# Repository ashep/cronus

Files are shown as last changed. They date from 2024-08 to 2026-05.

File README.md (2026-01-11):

# Cronus

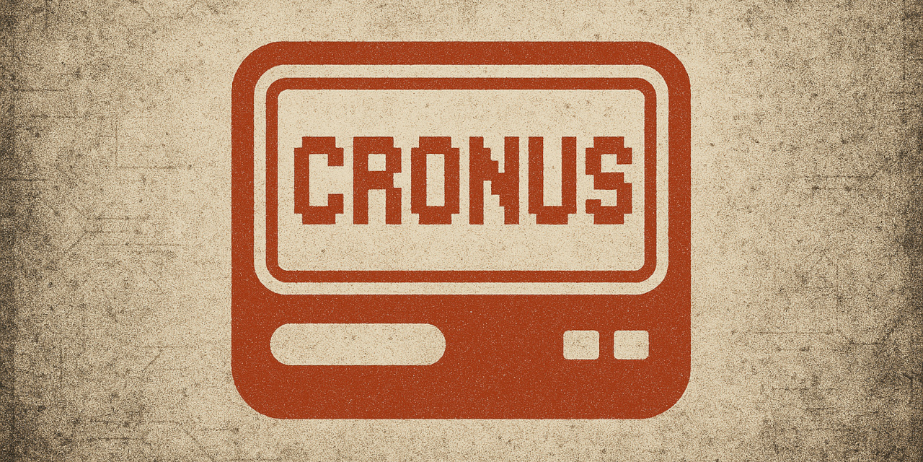
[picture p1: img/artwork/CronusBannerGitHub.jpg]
Banner


**Cronus** is a minimalistic digital clock built on top of the ESP32 MCU with the following features in mind.

- Show the current time, date, and weather conditions.
- Simple, with a bright display.
- Brightness auto-adjustment depending on the ambient light level.
- No buttons.
- Automatic Over-the-Air firmware upgrades.
- No disgusting bloody Arduino.

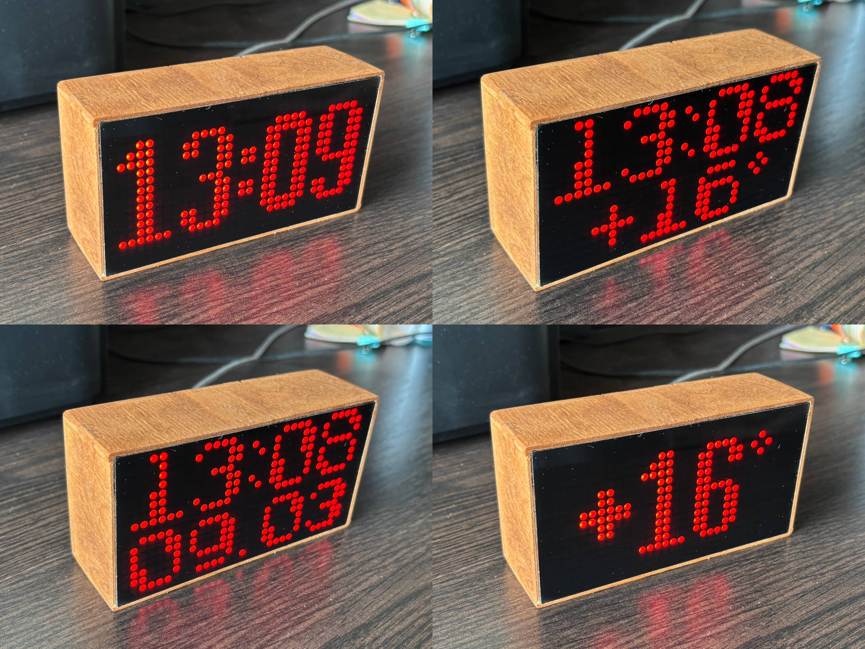
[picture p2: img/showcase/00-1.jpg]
Showcase

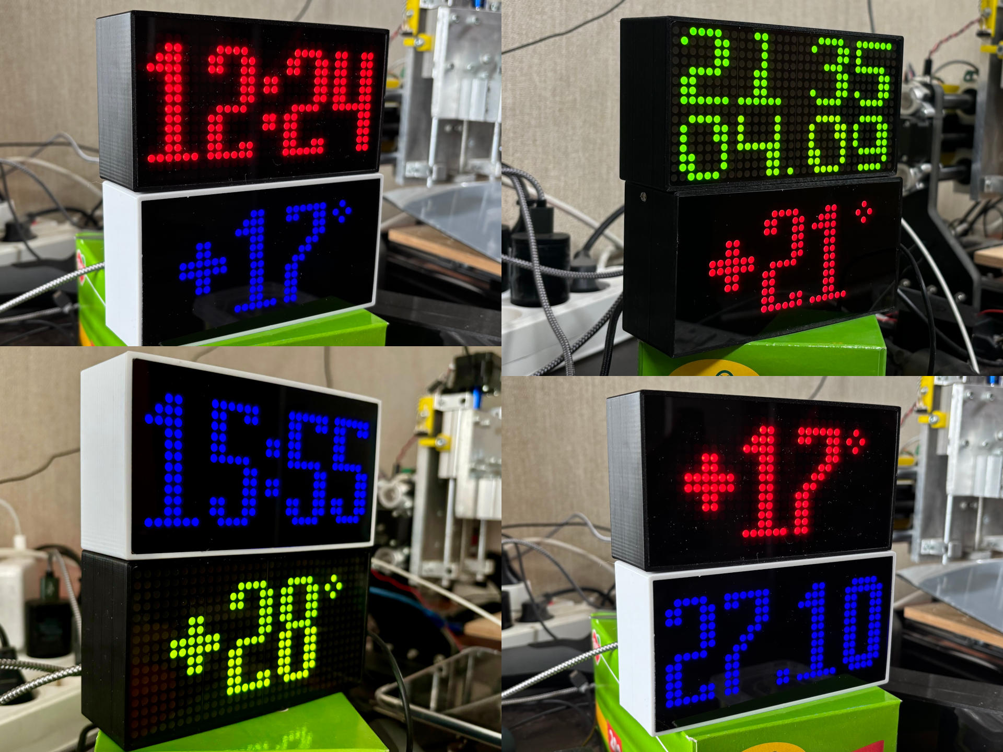
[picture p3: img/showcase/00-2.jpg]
Showcase


<details>
<summary>See more</summary>

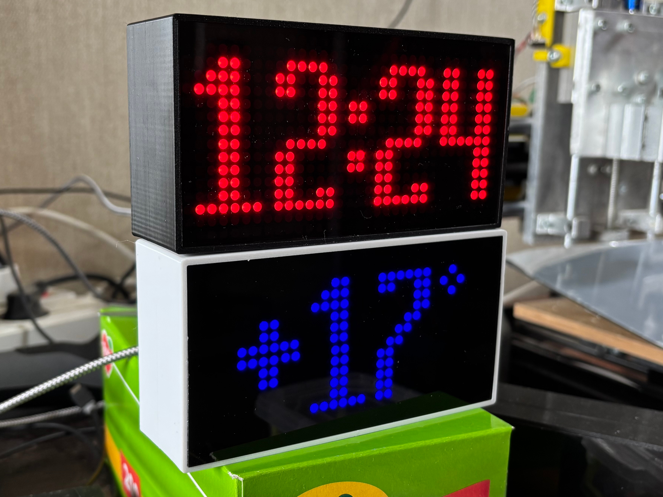
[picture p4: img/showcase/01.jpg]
Showcase

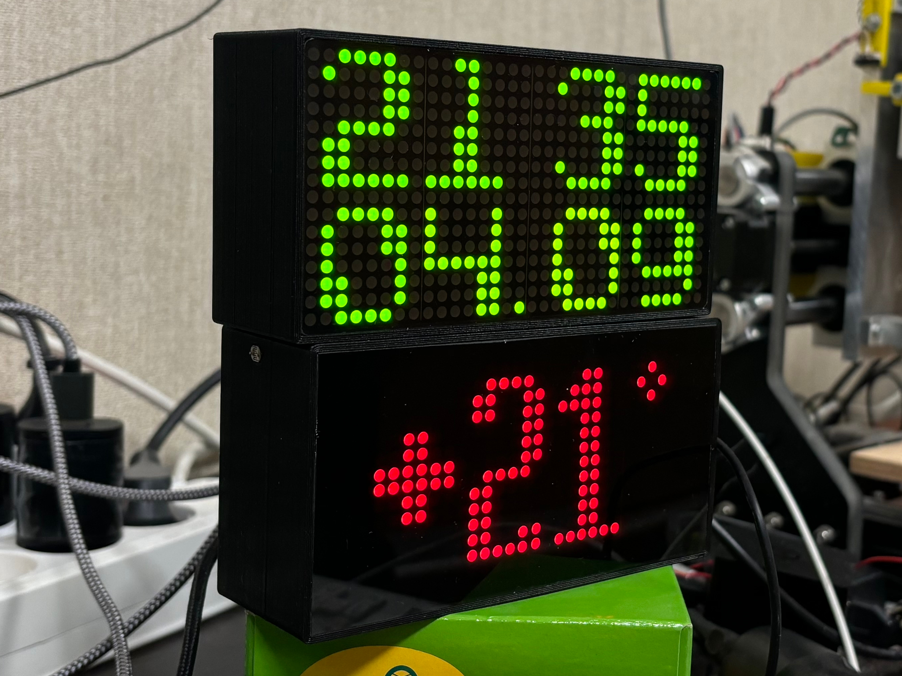
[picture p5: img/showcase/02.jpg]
Showcase

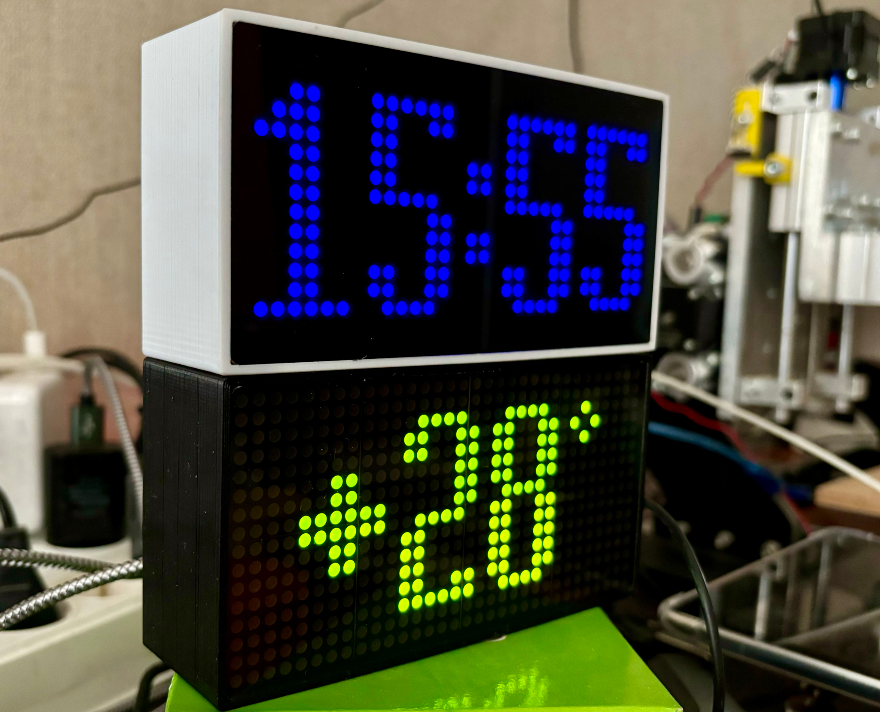
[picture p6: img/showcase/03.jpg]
Showcase

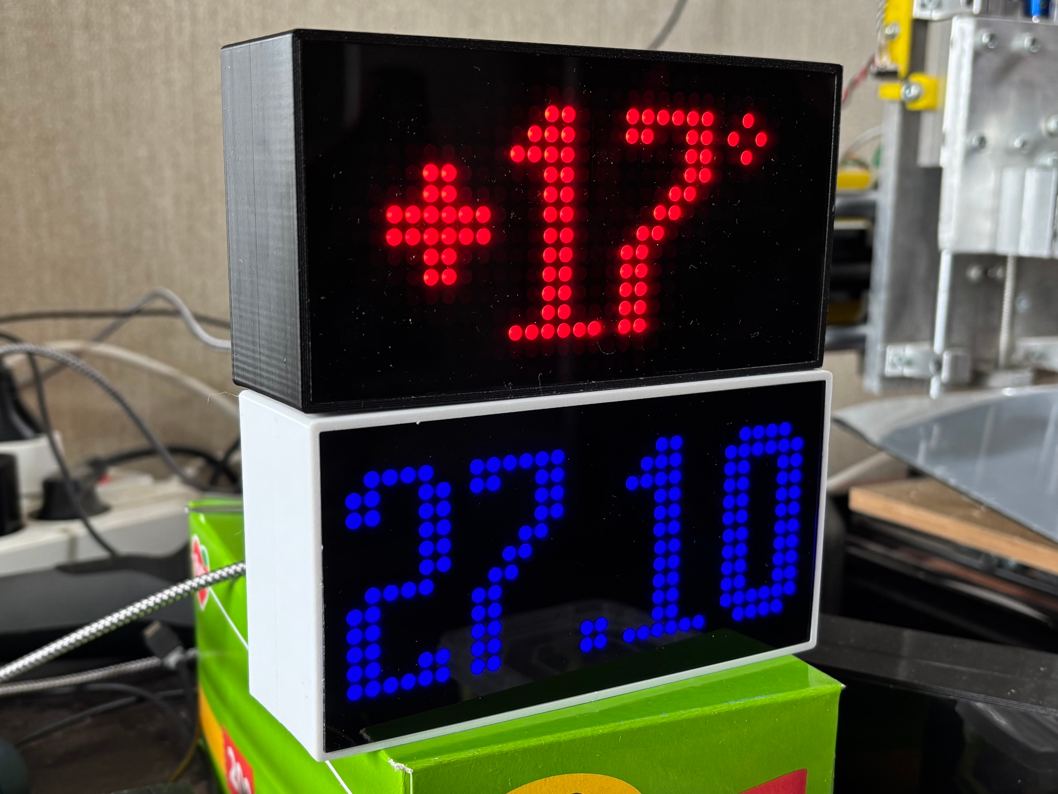
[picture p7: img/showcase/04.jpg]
Showcase

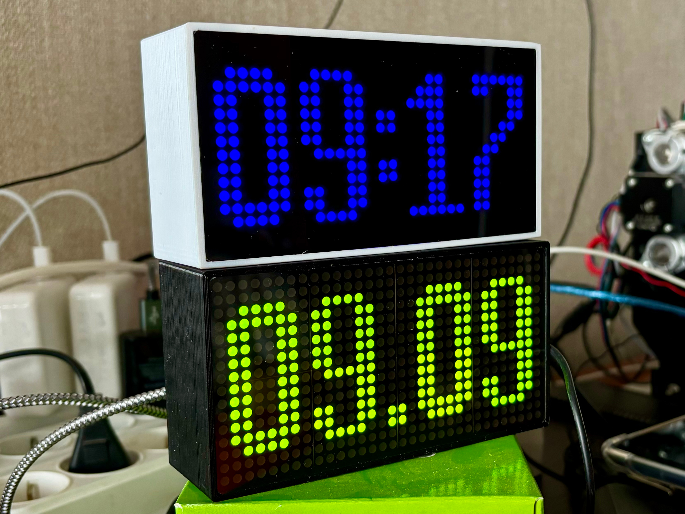
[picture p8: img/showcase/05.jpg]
Showcase

</details>

## How to make it

See the [Wiki](https://github.com/ashep/cronus/wiki).

## Contributing

Clone the repo:

```shell
git clone --recurse-submodules https://github.com/ashep/cronus.git
```

Or update an already cloned one to the latest version:

```shell
git pull
git submodule update --recursive --remote
```

## Changelog

### 0.0.5 (2026-01-11)

- Added [air raid alerts widget](https://github.com/ashep/cronus/issues/32).
- Added [a "busy" icon upon OTA](https://github.com/ashep/cronus/issues/23).
- Performance improvements and little optimizations.

### 0.0.4 (2025-09-30)

- Added [widget color](https://github.com/ashep/cronus/issues/26) options for colorful screens.
- Added [night mode](https://github.com/ashep/cronus/issues/28) options for colorful screens.

### 0.0.3 (2025-08-31)

- Added [night mode](https://github.com/ashep/cronus/issues/21) for colorful screens.
- Added [custom location](https://github.com/ashep/cronus/issues/13) option.
- Fixed [Wi-Fi reconnection](https://github.com/ashep/cronus/issues/18) at startup.

### 0.0.2 (2025-08-11)

- New Bluetooth configuration interface added.
- Weather icons added.

### 0.0.1 (2025-06-21)

First stable release.

## Authors

- [Oleksandr Shepetko](https://shepetko.com).

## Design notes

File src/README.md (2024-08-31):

# Cronus Firmware

## How to build

1. Install and [set up ESP-IDF].
2. `idf.py menuconfig`
3. Go to `Component config -> Cronus`, make necessary changes.
4. Exit saving changes.
5. `idf.py build`
6. `idf.py flash`

[set up ESP-IDF]: https://docs.espressif.com/projects/esp-idf/en/stable/esp32/get-started/index.html#installation

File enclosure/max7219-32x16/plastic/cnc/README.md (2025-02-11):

# Cronus Front Glass

This G-code is made for CNC milling of 2.4 mm acrylic glass using a 1 mm flute bit.

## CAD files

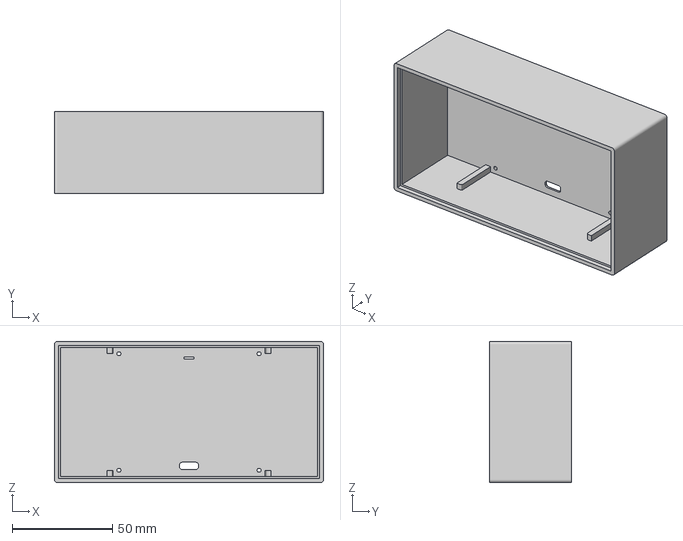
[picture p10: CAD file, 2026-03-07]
enclosure/max7219-32x16/plastic/3d-print/Enclosure.3mf
134.4 x 41.0 x 70.6 mm

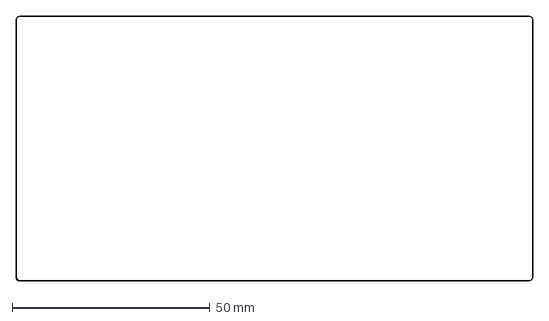
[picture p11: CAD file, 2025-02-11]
enclosure/max7219-32x16/plastic/dxf/FrontGlass.dxf
130.4 x 66.8 mm

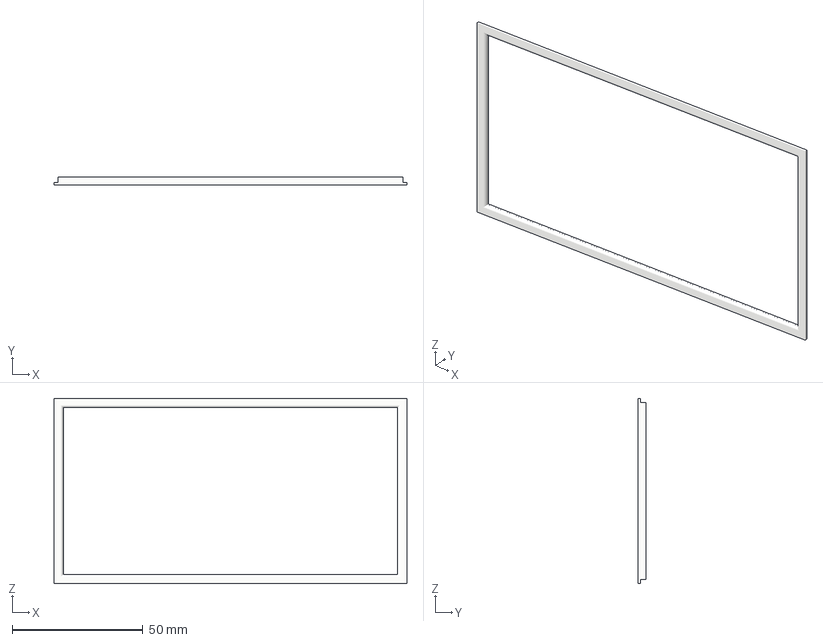
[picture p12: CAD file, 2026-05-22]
enclosure/max7219-32x16/plywood/3d-print/FrontGlassShim.3mf
135.0 x 2.90 x 70.8 mm

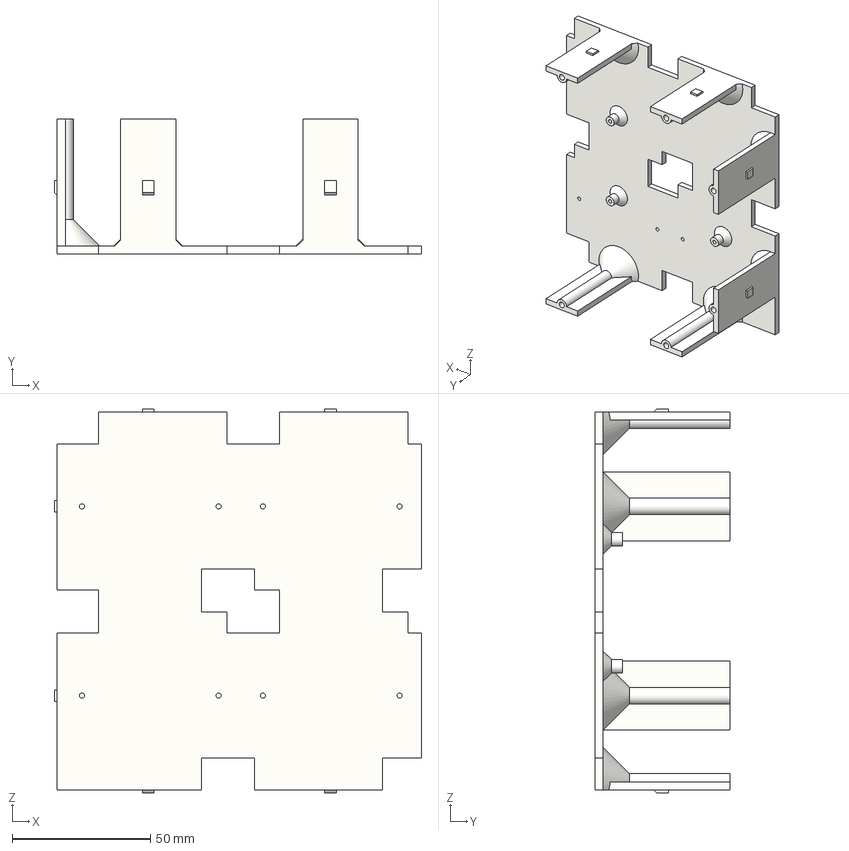
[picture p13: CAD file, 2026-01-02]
enclosure/ws2812-32x16/3d-print/DisplayMountLeft.3mf
133.0 x 49.0 x 139.0 mm

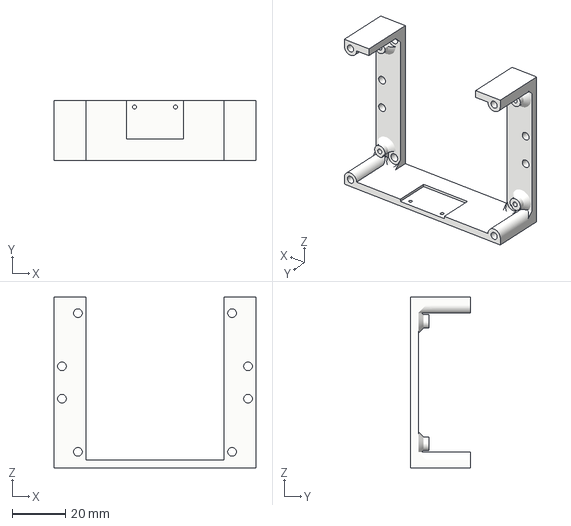
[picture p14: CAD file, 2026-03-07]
enclosure/max7219-32x16/plastic/3d-print/DisplayMount.3mf
76.0 x 22.7 x 64.2 mm

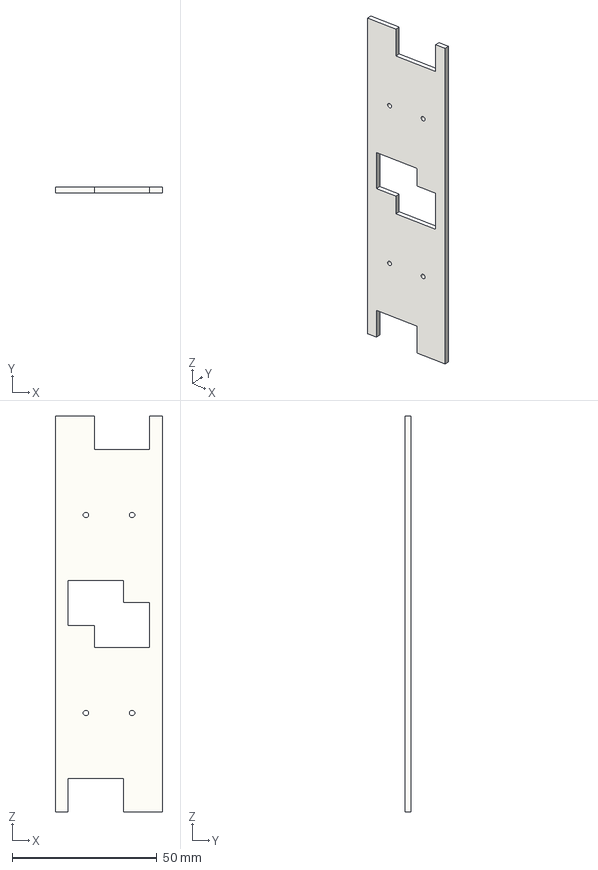
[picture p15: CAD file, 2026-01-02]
enclosure/ws2812-32x16/3d-print/DisplayMountConnector.3mf
37.0 x 2.00 x 137.0 mm

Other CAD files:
enclosure/ws2812-32x16/3d-print/DisplayMountRight.3mf
enclosure/max7219-32x16/plastic/CronusPlastic.f3d
enclosure/ws2812-32x16/Cronus.f3d

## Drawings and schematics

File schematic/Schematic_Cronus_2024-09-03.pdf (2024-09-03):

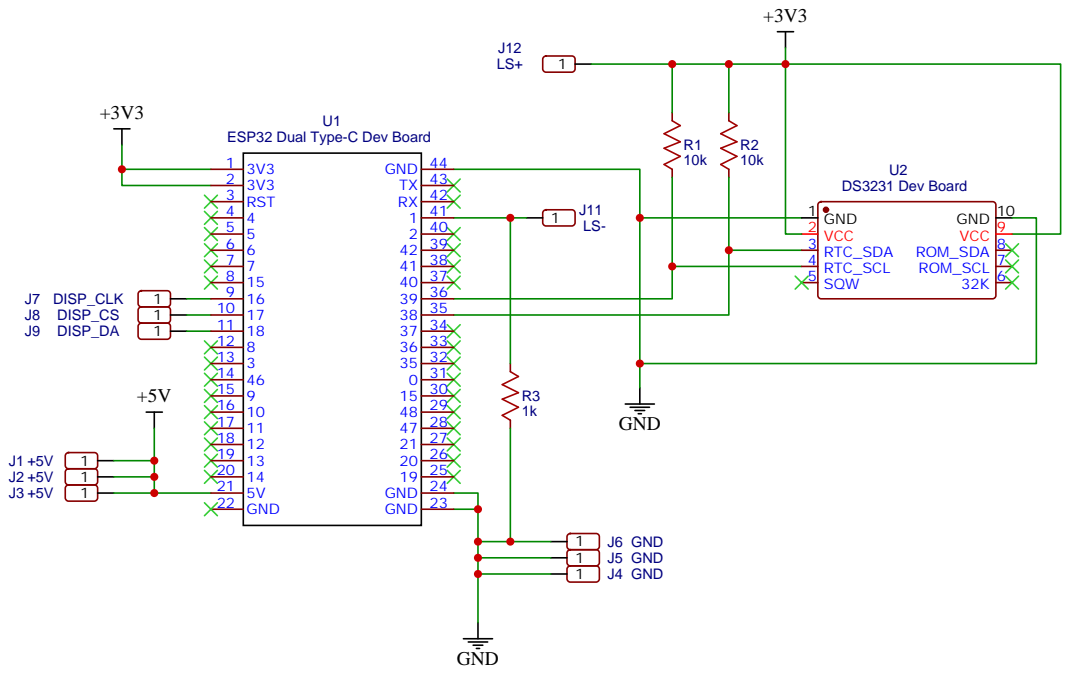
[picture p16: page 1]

Drawn By: Oleksandr Shepetko

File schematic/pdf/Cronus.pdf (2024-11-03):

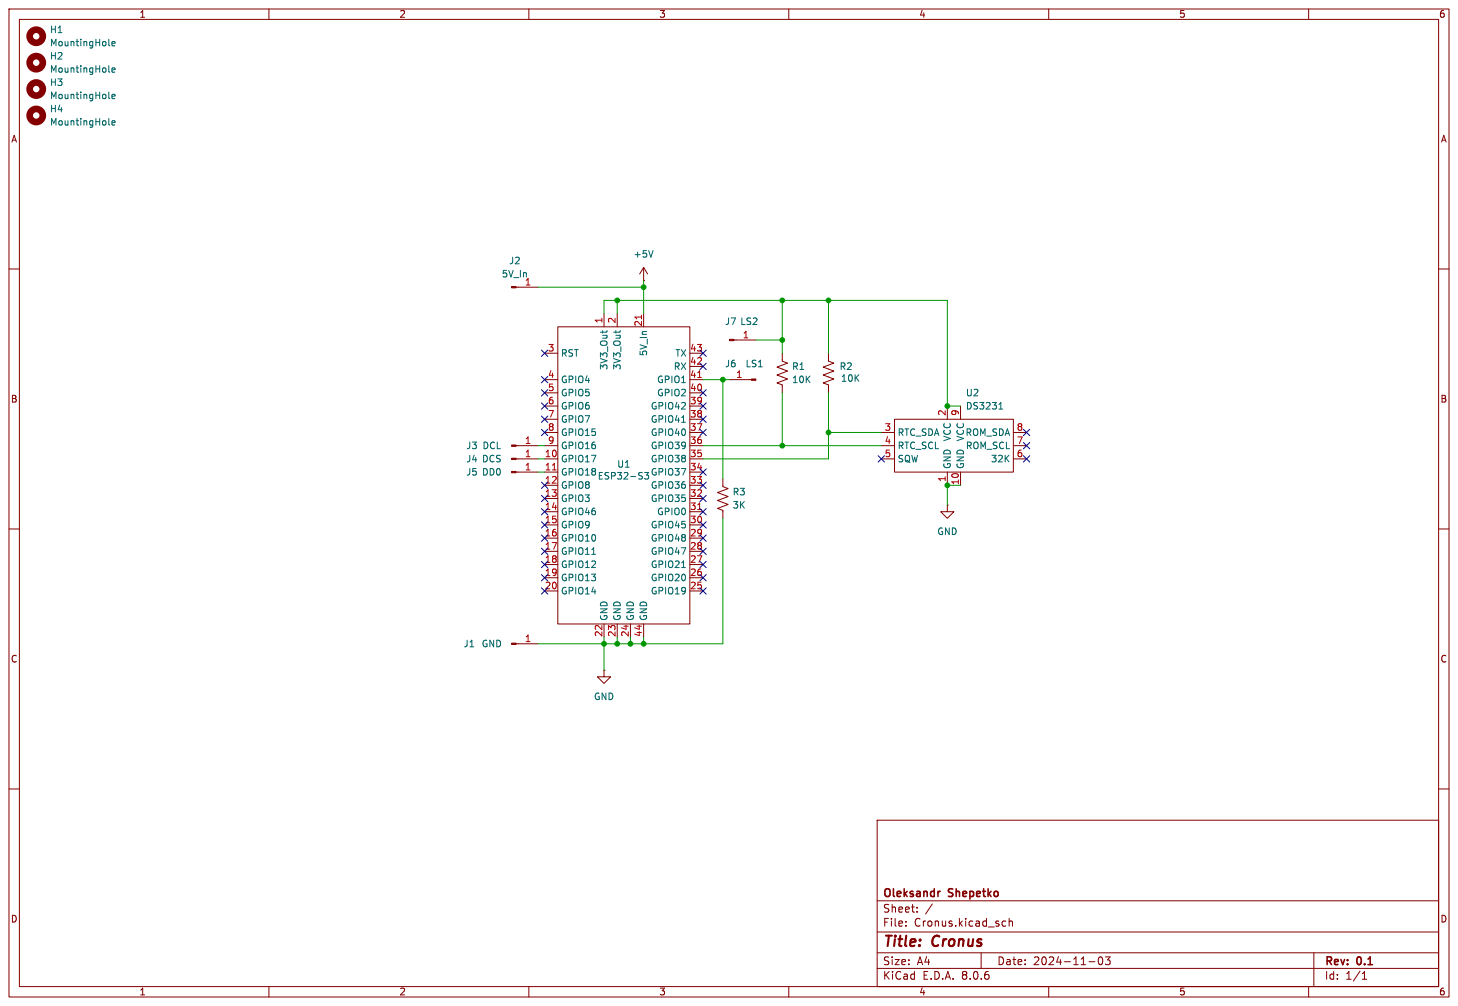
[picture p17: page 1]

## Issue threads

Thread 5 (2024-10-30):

Boot is halted in case if external RTC does not respond

ashep, 2024-10-30:

ashep, 2024-11-03:
Fixed in https://github.com/ashep/d5y/commit/fec575ab20989c3dba0f918175b4d31171c15e7e

Closed 2024-11-03.

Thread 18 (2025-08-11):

Add Wi-Fi reconnection attempts at startup

ashep, 2025-08-11:
If the first Wi-Fi connection attempt fails at the boot stage, the device should keep trying to reconnect.

It should only do this if the Wi-Fi connection was previously configured.

Closed 2025-08-31.

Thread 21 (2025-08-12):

Add night mode for screens displays

ashep, 2025-08-12:
WS2812 5mm LEDs are too bright in a dark room when emitting combined colors of light, i.e., not a single-channel color, like R, G, or B.

The idea is to have a "night mode": when the light sensor reports a zero light level, the display is automatically switched to a single-color mode. The best color is red, but users should be able to set it up.

The first iteration can use a fixed red color and an always-enabled night mode.

Closed 2025-08-12.

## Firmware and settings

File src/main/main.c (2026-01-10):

#include "cronus/cfg.h"
#include "cronus/bt.h"
#include "cronus/weather.h"
#include "cronus/air_raid.h"
#include "cronus/screen.h"
#include "cronus/brightness.h"

#ifdef CONFIG_CRONUS_DISPLAY_0_DRIVER_MAX7219_32X16
#include "dy/display_driver_max7219.h"
#elifdef CONFIG_CRONUS_DISPLAY_0_DRIVER_WS2812_32X16
#include "dy/display_driver_ws2812.h"
#endif

#include <string.h>
#include "esp_log.h"
#include "esp_event.h"
#include "nvs.h"
#include "nvs_flash.h"
#include "dy/error.h"
#include "dy/appinfo.h"
#include "dy/cfg2.h"
#include "dy/rtc.h"
#include "dy/net.h"
#include "dy/net_cfg.h"
#include "dy/ds3231.h"
#include "dy/cloud.h"

#define LTAG "MAIN"

static dy_ds3231_handle_t ds3231;

static dy_err_t init_nvs() {
    esp_err_t esp_err;

    esp_err = nvs_flash_init();
    if (esp_err == ESP_ERR_NVS_NO_FREE_PAGES || esp_err == ESP_ERR_NVS_NEW_VERSION_FOUND) {
        if ((esp_err == nvs_flash_erase()) != ESP_OK) {
            return dy_err(DY_ERR_FAILED, "nvs_flash_erase failed: %s", esp_err_to_name(esp_err));
        }

        if ((esp_err == nvs_flash_init()) != ESP_OK) {
            return dy_err(DY_ERR_FAILED, "nvs_flash_init failed: %s", esp_err_to_name(esp_err));
        }
    } else if (esp_err != ESP_OK) {
        return dy_err(DY_ERR_FAILED, "nvs_flash_init failed: %s", esp_err_to_name(esp_err));
    }

    return dy_ok();
}

static dy_err_t init_rtc() {
    dy_err_t err;
#ifdef CONFIG_CRONUS_DS3231_ENABLED
    err = dy_ds3231_init(CONFIG_CRONUS_DS3231_PIN_SCL, CONFIG_CRONUS_DS3231_PIN_SDA, &ds3231);
    if (dy_is_err(err)) {
        return err;
    }
    ESP_LOGI(LTAG, "DS3231 initialized; scl=%d; sda=%d", CONFIG_CRONUS_DS3231_PIN_SCL, CONFIG_CRONUS_DS3231_PIN_SDA);

    if (dy_is_err(err = dy_rtc_init(&ds3231))) {
        return err;
    }
#else
        if (dy_is_err(err = dy_rtc_init(NULL))) {
            return err;
        }
#endif

    ESP_LOGI(LTAG, "RTC initialized");

    return dy_ok();
}

#ifdef CONFIG_CRONUS_DISPLAY_0_DRIVER_MAX7219_32X16

static dy_err_t init_display_max7219() {
    dy_err_t err = dy_display_driver_max7219_init(
        0,
        CONFIG_CRONUS_DISPLAY_0_DRIVER_MAX7219_32X16_PIN_CS,
        CONFIG_CRONUS_DISPLAY_0_DRIVER_MAX7219_32X16_PIN_CLK,
        CONFIG_CRONUS_DISPLAY_0_DRIVER_MAX7219_32X16_PIN_DATA,
        4,
        2,
        true
    );
    if (dy_is_err(err)) {
        return err;
    }

    ESP_LOGI(LTAG, "MAX7219 display driver initialized; cs=%d; clk=%d; data=%d",
             CONFIG_CRONUS_DISPLAY_0_DRIVER_MAX7219_32X16_PIN_CS,
             CONFIG_CRONUS_DISPLAY_0_DRIVER_MAX7219_32X16_PIN_CLK,
             CONFIG_CRONUS_DISPLAY_0_DRIVER_MAX7219_32X16_PIN_DATA
    );

    return dy_ok();
}

#endif // CONFIG_CRONUS_DISPLAY_0_DRIVER_MAX7219_32X16

#ifdef CONFIG_CRONUS_DISPLAY_0_DRIVER_WS2812_32X16

static dy_err_t init_display_ws2812() {
    dy_err_t err = dy_display_driver_ws2812_init(
        0,
        CONFIG_CRONUS_DISPLAY_0_DRIVER_WS2812_32X16_PIN_DATA,
        (dy_display_driver_ws2812_segments_config_t) {
            .ppx = 8,
            .ppy = 8,
            .cols = 4,
            .rows = 2,
        });
    if (dy_is_err(err)) {
        return err;
    }

    ESP_LOGI(LTAG, "WS2812 display driver initialized; data=%d; nx=%d; ny=%d",
             CONFIG_CRONUS_DISPLAY_0_DRIVER_WS2812_32X16_PIN_DATA, 4, 2);

    return dy_ok();
}

#endif // CONFIG_CRONUS_DISPLAY_0_DRIVER_WS2812_32X16

static dy_err_t init_display() {
    dy_err_t err;
#ifdef CONFIG_CRONUS_DISPLAY_0_DRIVER_MAX7219_32X16
    err = init_display_max7219();
#elifdef CONFIG_CRONUS_DISPLAY_0_DRIVER_WS2812_32X16
    err = init_display_ws2812();
#else
    err = dy_err(DY_ERR_NOT_CONFIGURED, "no display driver set");
#endif

    return err;
}

static char *hwid() {
#ifdef CONFIG_CRONUS_DISPLAY_0_DRIVER_MAX7219_32X16
    return "max7219v32x16";
#elifdef CONFIG_CRONUS_DISPLAY_0_DRIVER_WS2812_32X16
    return "ws2812v32x16";
#else
    return "unknown";
#endif
}

void app_main(void) {
    esp_err_t esp_err;
    dy_err_t err;

    int v_maj, v_min, v_patch, v_alpha;
    int sn = sscanf(APP_VERSION, "%d.%d.%d.%d", &v_maj, &v_min, &v_patch, &v_alpha);
    if (sn == 3) {
        v_alpha = 0;
    } else if (sn != 4) {
        v_maj = 0;
        v_min = 0;
        v_patch = 0;
    }
    ESP_LOGI(LTAG, "APP_VERSION: %s; parsed: %d.%d.%d.%d", APP_VERSION, v_maj, v_min, v_patch, v_alpha);

    // App info, MUST be set before any other operations
    dy_appinfo_info_t app_info = {
        .owner = APP_OWNER,
        .name = APP_NAME,
        .hwid = hwid(),
        .ver = {
            .major = v_maj,
            .minor = v_min,
            .patch = v_patch,
            .alpha = v_alpha,
        },
        .auth = "", // will be set later
    };
    dy_appinfo_set(&app_info);

    // Event loop
    if ((esp_err = esp_event_loop_create_default()) != ESP_OK) {
        ESP_LOGE(LTAG, "esp_event_loop_create_default: %s", esp_err_to_name(esp_err));
        abort();
    }

    // NVS
    if (dy_is_err(err = init_nvs())) {
        ESP_LOGE(LTAG, "init_nvs: %s", dy_err_str(err));
        abort();
    }

    // Config, MUST be called right AFTER init_nvs(), but BEFORE further initialization
    if (dy_is_err(err = init_config())) {
        ESP_LOGE(LTAG, "init_config: %s", dy_err_str(err));
        abort();
    }

    float lat = 0;
    if (dy_is_err(err = dy_cfg2_get_float_dft(CRONUS_CFG_ID_LOCATION_LAT, &lat, 0))) {
        ESP_LOGE(LTAG, "dy_cfg2_get_float(CRONUS_CFG_ID_LOCATION_LAT): %s", dy_err_str(err));
    }
    float lng = 0;
    if (dy_is_err(err = dy_cfg2_get_float_dft(CRONUS_CFG_ID_LOCATION_LNG, &lng, 0))) {
        ESP_LOGE(LTAG, "dy_cfg2_get_float(CRONUS_CFG_ID_LOCATION_LNG): %s", dy_err_str(err));
    }
    dy_cloud_set_location(lat, lng);

    // Display
    if (dy_is_err(err = init_display())) {
        ESP_LOGE(LTAG, "init_display: %s", dy_err_str(err));
        abort();
    }

    // RTC
    if (dy_is_err(err = init_rtc())) {
        ESP_LOGE(LTAG, "init_rtc: %s", dy_err_str(err));
    }

    // Network
    if (dy_is_err(err = dy_net_init())) {
        ESP_LOGE(LTAG, "dy_net_init: %s", dy_err_str(err));
        abort();
    }

    // Network config service
    if (dy_is_err(err = dy_net_cfg_init())) {
        ESP_LOGE(LTAG, "dy_net_cfg_init: %s", dy_err_str(err));
    }

    // Bluetooth
    if (dy_is_err(err = cronus_bt_init())) {
        ESP_LOGE(LTAG, "cronus_bt_init: %s", dy_err_str(err));
    }

    // Time sync
    if (dy_is_err(err = dy_cloud_time_scheduler_start())) {
        ESP_LOGE(LTAG, "dy_cloud_time_scheduler_start: %s", dy_err_str(err));
    }

    // Weather sync
    if (dy_is_err(err = cronus_weather_init())) {
        ESP_LOGE(LTAG, "cronus_weather_init: %s", dy_err_str(err));
    }

    // Air raid alerts sync
    if (dy_is_err(err = cronus_air_raid_alert_init())) {
        ESP_LOGE(LTAG, "cronus_air_raid_alert_init: %s", dy_err_str(err));
    }

    // Firmware update scheduler
    uint8_t allow_alpha = 0;
    if (dy_is_err(err = dy_cfg2_get_u8_dft(CRONUS_CFG_ID_ALLOW_UNSTABLE_FW, &allow_alpha, 0))) {
        ESP_LOGE(LTAG, "get CRONUS_CFG_ID_ALLOW_UNSTABLE_FW: %s", dy_err_str(err));
    } else {
        if (dy_is_err(err = dy_cloud_fwupdate_scheduler_start((bool) allow_alpha))) {
            ESP_LOGE(LTAG, "dy_cloud_fwupdate_scheduler_start: %s", dy_err_str(err));
        }
    }

    // Brightness monitor
    if (dy_is_err(err = cronus_brightness_monitor_init())) {
        ESP_LOGE(LTAG, "cronus_brightness_monitor_init: %s", dy_err_str(err));
    }

    // Screen
    if (dy_is_err(err = cronus_screen_init())) {
        ESP_LOGE(LTAG, "cronus_screen_init: %s", dy_err_str(err));
        abort();
    }
}

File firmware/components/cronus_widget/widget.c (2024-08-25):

#include <sys/cdefs.h>
#include <stdio.h>
#include <string.h>
#include <time.h>

#include "freertos/FreeRTOS.h"
#include "esp_log.h"
#include "esp_event.h"
#include "esp_adc/adc_oneshot.h"

#include "dy/error.h"
#include "dy/display.h"
#include "dy/gfx/gfx.h"
#include "dy/gfx/text.h"
#include "dy/gfx/font/clock/6x7v1.h"
#include "dy/gfx/font/clock/6x8v1.h"
#include "dy/gfx/font/clock/6x12v1.h"
#include "dy/cloud.h"

#include "cronus/widget.h"
#include "cronus/cfg.h"

#define LTAG "CRONUS_WIDGET"
#define FMT_TEMP_ZERO "%d*"
#define FMT_TEMP_NON_ZERO "%+d*"

typedef enum {
    SHOW_CYCLE_TIME,
    SHOW_CYCLE_DATE,
    SHOW_CYCLE_DOW,
    SHOW_CYCLE_AMB_TEMP,
    SHOW_CYCLE_ODR_TEMP,
    SHOW_CYCLE_MAX,
} show_cycle_num;

static SemaphoreHandle_t mux;
static int cur_cycle = SHOW_CYCLE_TIME;

static time_t weather_ts;
static dy_cloud_weather_t weather;

#ifdef CONFIG_CRONUS_LIGHT_SENSOR_ENABLED
static adc_oneshot_unit_handle_t adc_handle;
static int adc_light_out;
#endif // CONFIG_CRONUS_LIGHT_SENSOR_ENABLED

#ifdef CONFIG_CRONUS_LIGHT_SENSOR_ENABLED
_Noreturn static void fetch_light_data_task() {
    dy_err_t err;
    esp_err_t esp_err;
    uint8_t min_b, max_b, cur_b;

    while (1) {
        vTaskDelay(pdMS_TO_TICKS(3000));

        min_b = cronus_cfg_get_min_brightness();
        max_b = cronus_cfg_get_max_brightness();

        esp_err = adc_oneshot_read(adc_handle, CONFIG_CRONUS_LIGHT_SENSOR_ADC_CHANNEL, &adc_light_out);
        if (esp_err != ESP_OK) {
            ESP_LOGE(LTAG, "adc_oneshot_read: %s", esp_err_to_name(esp_err));
            continue;
        }

        cur_b = (adc_light_out / 16) >> 4;

        if (cur_b < min_b) {
            cur_b = min_b;
        }

        if (cur_b > max_b) {
            cur_b = max_b;
        }

        err = dy_display_set_brightness(0, cur_b);
        if (dy_nok(err)) {
            ESP_LOGI(LTAG, "dy_display_set_brightness: %s", dy_err_str(err));
            continue;
        }
    }
}
#endif // CONFIG_CRONUS_LIGHT_SENSOR_ENABLED

static void weather_update_handler(void *arg, esp_event_base_t base, int32_t id, void *data) {
    dy_cloud_weather_t *dt = (dy_cloud_weather_t *) data;

    strncpy(weather.title, dt->title, DY_CLOUD_WEATHER_TITLE_LEN);
    weather.temp = dt->temp;
    weather.feels = dt->feels;
    weather.pressure = dt->pressure;
    weather.humidity = dt->humidity;

    weather_ts = time(NULL);

    ESP_LOGI(LTAG, "weather updated");
}

_Noreturn static void switch_cycle_task() {
    uint8_t delay = 0;
    uint8_t new_cycle;
    time_t now;

    while (1) {
        vTaskDelay(pdMS_TO_TICKS(1000 * (delay ? delay : 5)));
        now = time(NULL);

        // Search for the next cycle having non-zero delay
        delay = 0;
        new_cycle = cur_cycle;
        for (int i = 0; i < SHOW_CYCLE_MAX && delay == 0; i++) {
            ++new_cycle;
            if (new_cycle >= SHOW_CYCLE_MAX) {
                new_cycle = SHOW_CYCLE_TIME;
            }

            switch (new_cycle) {
                case SHOW_CYCLE_TIME:
                    // Time string is always shown in multiline mode
                    if (!cronus_cfg_get_multiline_mode()) {
                        delay = cronus_cfg_get_show_time_dur();
                    }
                    break;
                case SHOW_CYCLE_DATE:
                    delay = cronus_cfg_get_show_date_dur();
                    break;
                case SHOW_CYCLE_DOW:
                    delay = cronus_cfg_get_show_dow_dur();
                    break;
                case SHOW_CYCLE_AMB_TEMP:
                    delay = cronus_cfg_get_show_amb_temp_dur();
                    break;
                case SHOW_CYCLE_ODR_TEMP:
                    if (weather_ts > 0 && now - weather_ts < 1800) { // weather data older than 30 minutes is obsolete
                        delay = cronus_cfg_get_show_odr_temp_dur();
                    }
                    break;
                default:
                    ESP_LOGW(LTAG, "unexpected show cycle: %d", cur_cycle);
                    break;
            }
        }

        if (new_cycle == cur_cycle) {
            continue;
        }

        // Switch to the next cycle
        if (xSemaphoreTake(mux, portTICK_PERIOD_MS) != pdTRUE) {
            ESP_LOGE(LTAG, "xSemaphoreTake failed");
            continue;
        }
        cur_cycle = new_cycle;
        xSemaphoreGive(mux);
    }
}

static void render_max7219_32x16_single_line(
    dy_gfx_buf_t *buf,
    const char *time_str,
    const char *date_str,
    const char *odr_temp_str
) {
    uint8_t sc;
    int32_t x;

    if (xSemaphoreTake(mux, portTICK_PERIOD_MS) != pdTRUE) {
        ESP_LOGE(LTAG, "xSemaphoreTake failed");
        return;
    }
    sc = cur_cycle;
    xSemaphoreGive(mux);

    switch (sc) {
        case SHOW_CYCLE_TIME:
            dy_gfx_puts(buf, &dy_gfx_font_6x12v1, (dy_gfx_point_t) {1, 2}, time_str, 1, 1);
            break;
        case SHOW_CYCLE_DATE:
            dy_gfx_puts(buf, &dy_gfx_font_6x12v1, (dy_gfx_point_t) {1, 2}, date_str, 1, 1);
            break;
        case SHOW_CYCLE_DOW:
            // Not implemented
            break;
        case SHOW_CYCLE_AMB_TEMP:
            // Not implemented
            break;
        case SHOW_CYCLE_ODR_TEMP:
            x = 13;
            if (weather.feels > 9 || weather.feels < -9) {
                x = 4;
            } else if (weather.feels > 0 || weather.feels < 0) {
                x = 7;
            }
            dy_gfx_puts(buf, &dy_gfx_font_6x12v1, (dy_gfx_point_t) {x, 2}, odr_temp_str, 1, 1);
            break;
        default:
            break;
    }
}

static void render_max7219_32x16_multi_line(
    dy_gfx_buf_t *buf,
    const char *time_str,
    const char *date_str,
    const char *odr_temp_str
) {
    uint8_t sc;
    int32_t x;

    if (xSemaphoreTake(mux, portTICK_PERIOD_MS) != pdTRUE) {
        ESP_LOGE(LTAG, "xSemaphoreTake failed");
        return;
    }
    sc = cur_cycle;
    xSemaphoreGive(mux);

    dy_gfx_puts(buf, &dy_gfx_font_6x8v1, (dy_gfx_point_t) {1, 0}, time_str, 1, 1);

    switch (sc) {
        case SHOW_CYCLE_DATE:
            dy_gfx_puts(buf, &dy_gfx_font_6x7v1, (dy_gfx_point_t) {1, 9}, date_str, 1, 1);
            break;
        case SHOW_CYCLE_ODR_TEMP:
            x = 13;
            if (weather.feels > 9 || weather.feels < -9) {
                x = 5;
            } else if (weather.feels > 0 || weather.feels < 0) {
                x = 7;
            }
            dy_gfx_puts(buf, &dy_gfx_font_6x7v1, (dy_gfx_point_t) {x, 9}, odr_temp_str, 1, 1);
            break;
        default:
            break;
    }
}
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

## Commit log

2024-08-04 Add partitions.csv
    [partitions.csv]
2024-08-31 Tidy up file structure
    [partitions.csv]
2024-09-03 Add the schematic and PCB
    [Drill_NPTH_Through.DRL, Drill_PTH_Through.DRL, Drill_PTH_Through_Via.DRL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]
2024-09-07 Update schematic
    [Drill_NPTH_Through.DRL, Drill_PTH_Through.DRL, Drill_PTH_Through_Via.DRL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]
2024-10-07 Add sdkconfig.esp32s3
2024-10-12 firmware: fix rtc config load
    [main.c]
2024-10-13 Remake schematic with KiCad #3
    [Cronus.kicad_pcb, Cronus.kicad_sch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]
2024-10-24 Cleanup #3
    [Drill_NPTH_Through.DRL, Drill_PTH_Through.DRL, Drill_PTH_Through_Via.DRL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]
2024-11-07 Update board gerber and gcode
    [Cronus-B_Cu.gbr, Cronus-B_Fab.gbr, Cronus-B_Mask.gbr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]
2024-11-08 Add enclosure
    [BackCover.3mf, DisplayFixtureLeft.3mf, DisplayFixtureRight.3mf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]
2024-11-11 readme: add circuit info #2
2025-02-11 Add designs and manufaturing files
    [Back.3mf, Back.dxf, CronusPlastic.f3d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]
2025-02-12 Update plywood enclosure
    [CronusPlywood.f3z, TopBottom.dxf]
2025-02-13 Fix plywood front glass
    [CronusPlywood.f3z, FrontGlass.dxf]
2025-07-26 Update plywood enclosure g-codes
    [CronusPlywood.f3z]
2025-08-21 Fix PCB
    [Cronus-B_Cu.gbr, Cronus-B_Fab.gbr, Cronus-B_Mask.gbr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]
2025-09-21 Upd PCB
    [Cronus-B_Cu.gbr, Cronus-B_Fab.gbr, Cronus-B_Mask.gbr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]
2025-10-25 Add WS2812-32x16 enclosure
    [Back.3mf, Back.dxf, Cronus.f3d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]
2025-11-19 Update PCB
    [Cronus-B_Cu.gbr, Cronus-B_Fab.gbr, Cronus-B_Mask.gbr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]
2026-01-02 Update ws2812-32x16 enclosure
    [Cronus.f3d, DisplayMaskLeft.3mf, DisplayMaskRight.3mf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]
2026-03-07 enclosure/max7219-32x16 updated
    [Back.3mf, Back.dxf, DisplayMount.3mf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]
2026-03-08 Fix enclosure/max7219-32x16
2026-05-22 Upd enclosure
    [CronusPlywood.f3z, FrontGlassShim.3mf]
2026-11-07 Add max7219-32x16 4.5mm plywood enclosure
2026-11-07 Update max7219-32x16 4.5mm plywood enclosure
